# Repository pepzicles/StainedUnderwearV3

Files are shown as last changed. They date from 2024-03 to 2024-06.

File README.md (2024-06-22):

# Stained Underwear
### By Julia Daser and Pepi Ng

This project is awarded Grand Prize winner in University of Virginia's Open Call 'Data is Art', and is currently exhibited in U of Virginia's campus till the Dec 2024. 

Stained Underwear GIF

-------

### About the project

[Watch the video](https://www.youtube.com/watch?v=LS9jGnWLb5s)

This project aims to highlight the amount of time, resources and labour one spends coping with menstruation.

Our project sheds light on the often hidden and stigmatized inconveniences people face throughout their lifetime because of menstruation. We thus wish to proudly take ownership of our personal experiences with menstruation, and spark greater conversations around female reproductive health.

Pepi first collected the number of times in which they scrubbed individual underwear stained with menstrual blood over the course of 11 days. They also recorded the time in which they scrubbed their underwear each day. You can view this data in the CSV file in the "Menstrual Data" folder.

We then coded the robotic arm to scrub one of our (actual) period-stained underwear the respective number of times at the respective times of day. At the end of the 11 days, the dataset automatically starts again at Day 0. 

### Materials used

Robot Arm:
- 3 x [Servo Motors](https://www.hiwonder.com/products/ld-220mg?_pos=1&_sid=52fc990bb&_ss=r)
- 3D-printed Robot Arm base, middle and top
- M3 Screws
- [Clothes Scrubber](https://www.amazon.com/gp/product/B0CSWVYRTL/ref=ewc_pr_img_1?smid=A2RP8HJO7IWQV2&psc=1)

Sink:
- [Sink Base](https://www.amazon.com/gp/product/B0BXDFKQ64/ref=ppx_yo_dt_b_asin_title_o00_s00?ie=UTF8&psc=1)
- 3D-printed faucet and funnel
- Watertank [Food Storage](https://www.amazon.com/gp/product/B0030MY2Y0/ref=ewc_pr_img_1?smid=ATVPDKIKX0DER&th=1)
- [Waterpump](https://www.amazon.com/Gikfun-Aquarium-Cooled-Diaphragm-EK1856/dp/B0744FWNFR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)

Electronics:
- Arduino Uno
- 1000μF Capacitor
- [Precision RTC](https://www.adafruit.com/product/5188) (Clock)
- 6V 5A power supply
- Transistor 2n2222a

### Personalizing the project
Feel free to modify the project by editing the code/ 3D models/ dataset to suit your needs.

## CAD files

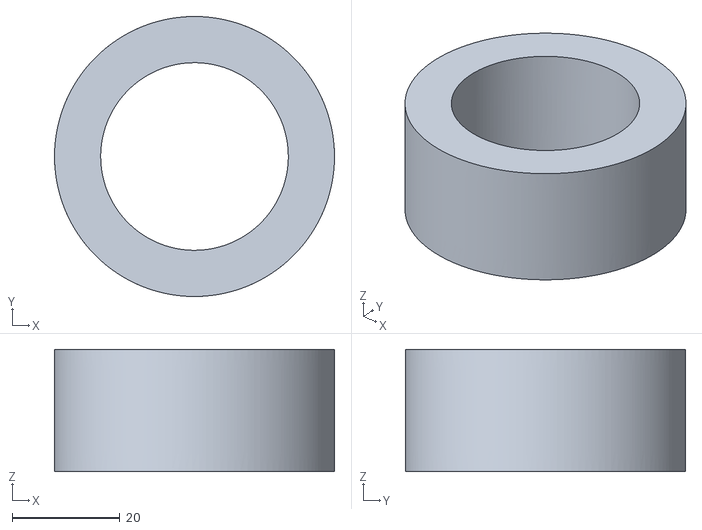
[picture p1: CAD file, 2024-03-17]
3D Models/Faucet/FaucetStopper.stl
51.9 x 51.9 x 22.6

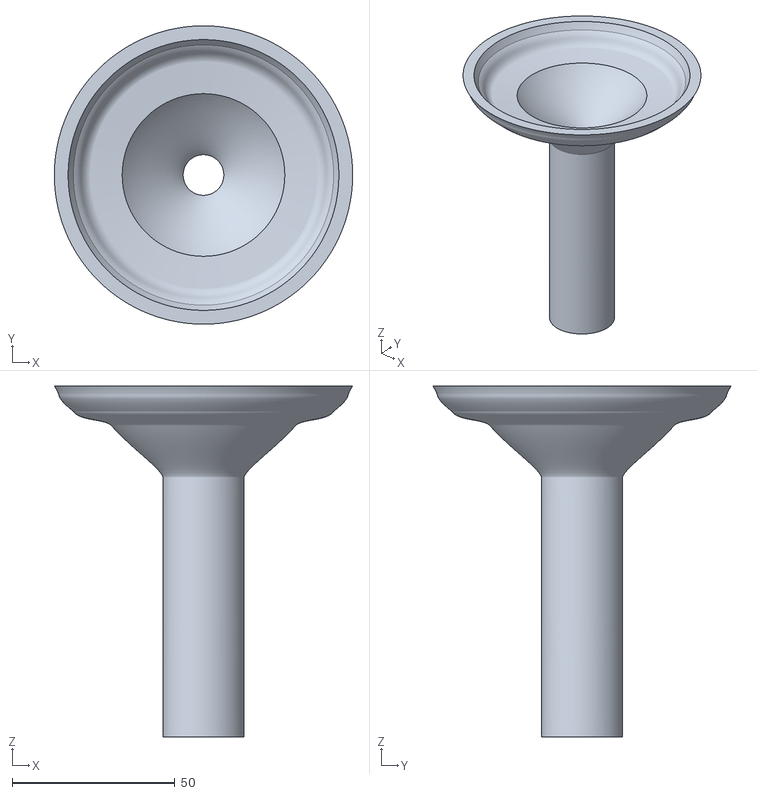
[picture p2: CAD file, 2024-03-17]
3D Models/Funnel.stl
91.7 x 91.7 x 107.9

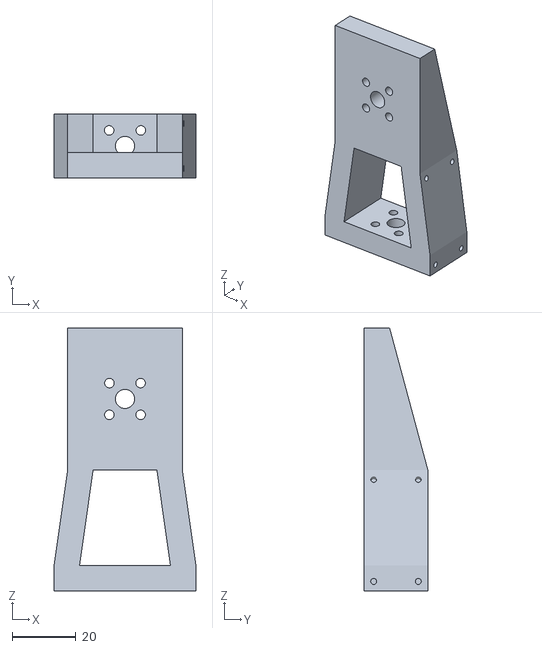
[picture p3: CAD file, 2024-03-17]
3D Models/Robot/Top.stl
44.5 x 20.0 x 82.5

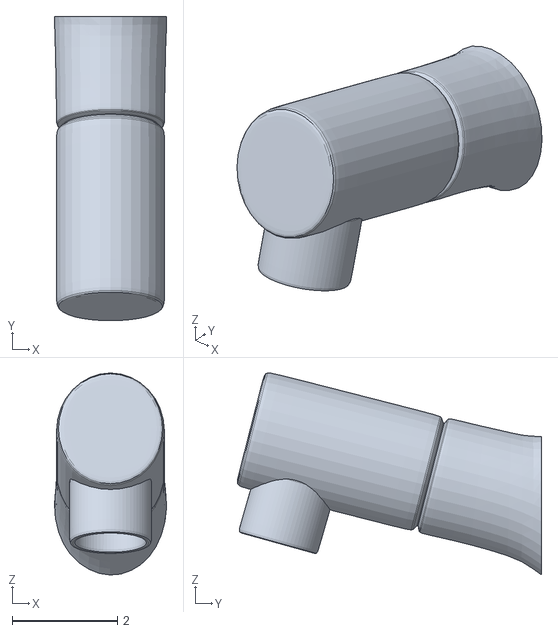
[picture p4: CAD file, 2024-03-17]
3D Models/Faucet/FaucetFront.stl
2.13 x 5.80 x 3.85

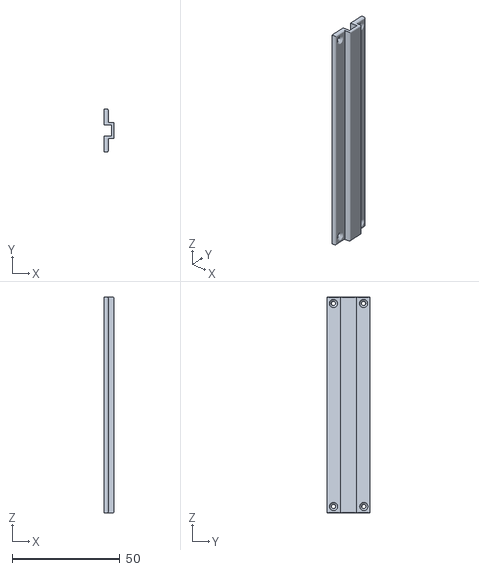
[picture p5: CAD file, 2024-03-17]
3D Models/Robot/WireHolderMiddle.stl
4.69 x 20.0 x 100.0

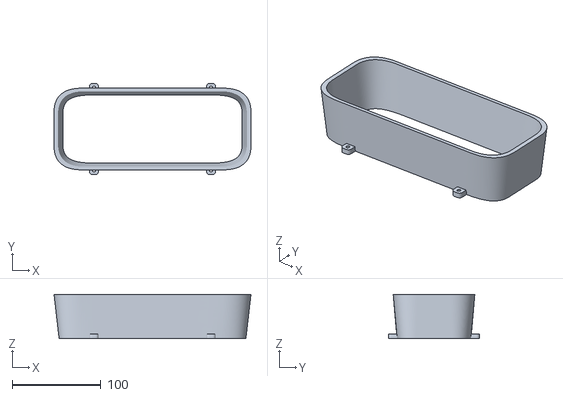
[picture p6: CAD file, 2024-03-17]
3D Models/WaterTankHolder.stl
222.3 x 102.7 x 50.0

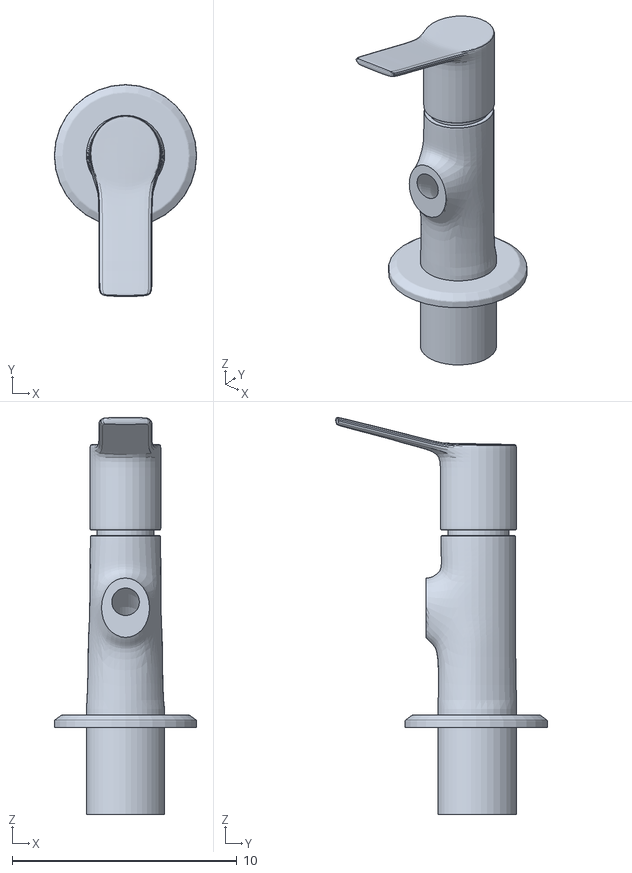
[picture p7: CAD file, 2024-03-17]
3D Models/Faucet/Faucet.stl
6.33 x 9.42 x 17.7

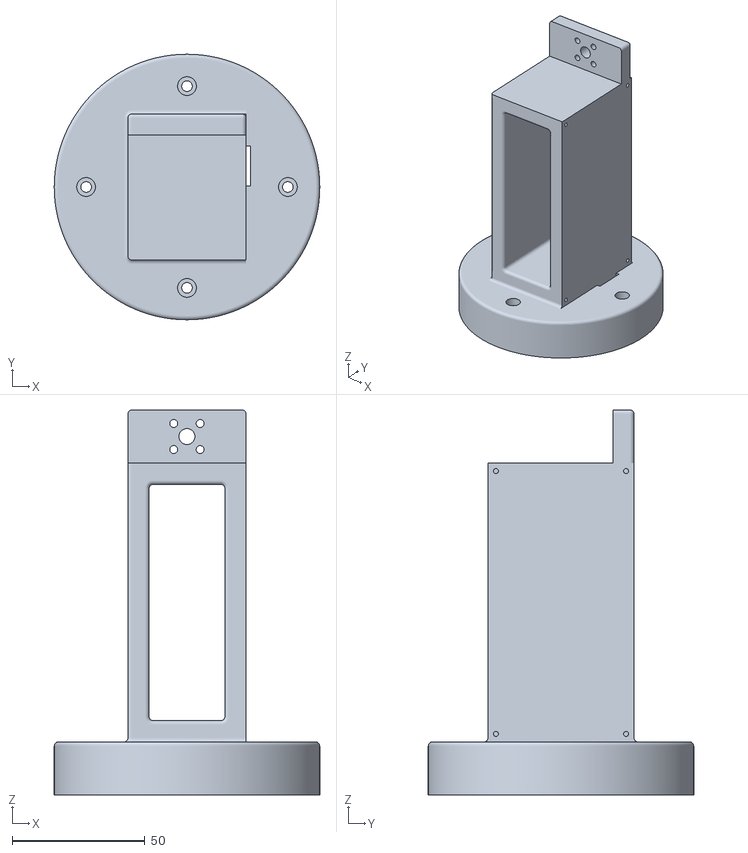
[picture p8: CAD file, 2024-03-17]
3D Models/Robot/Base.stl
100.0 x 100.0 x 145.0

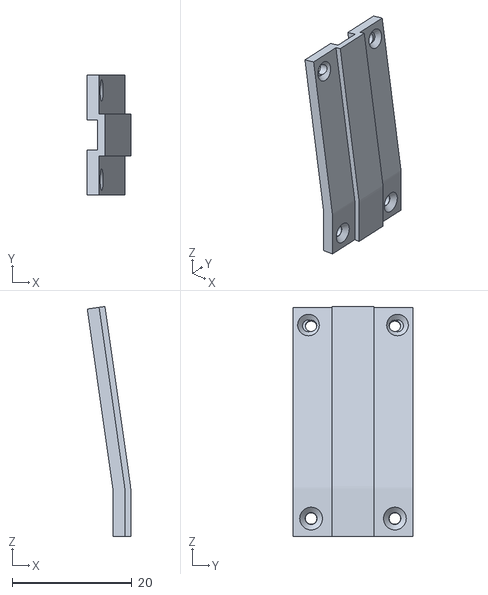
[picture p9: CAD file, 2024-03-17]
3D Models/Robot/WireHolderTop.stl
7.27 x 20.0 x 38.4

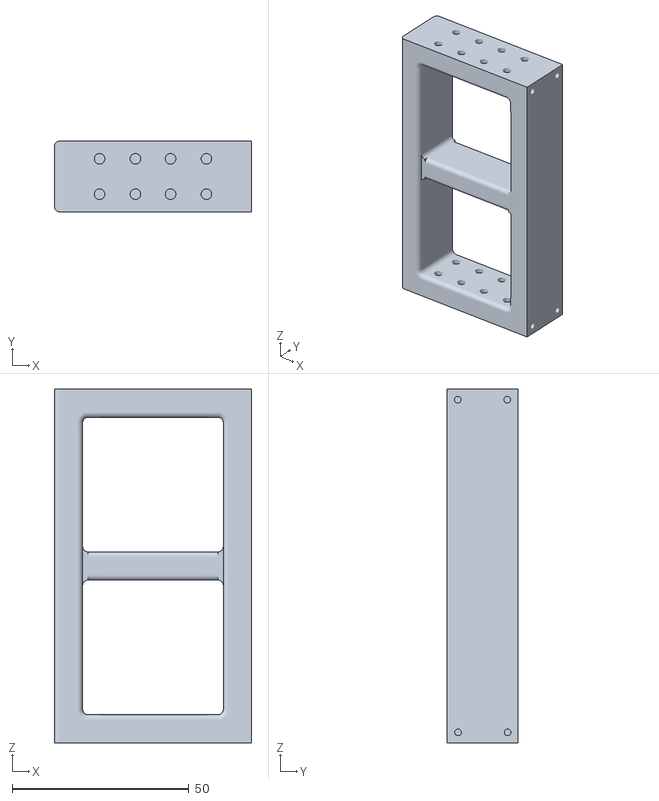
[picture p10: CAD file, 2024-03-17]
3D Models/Robot/Middle.stl
55.7 x 20.0 x 100.0

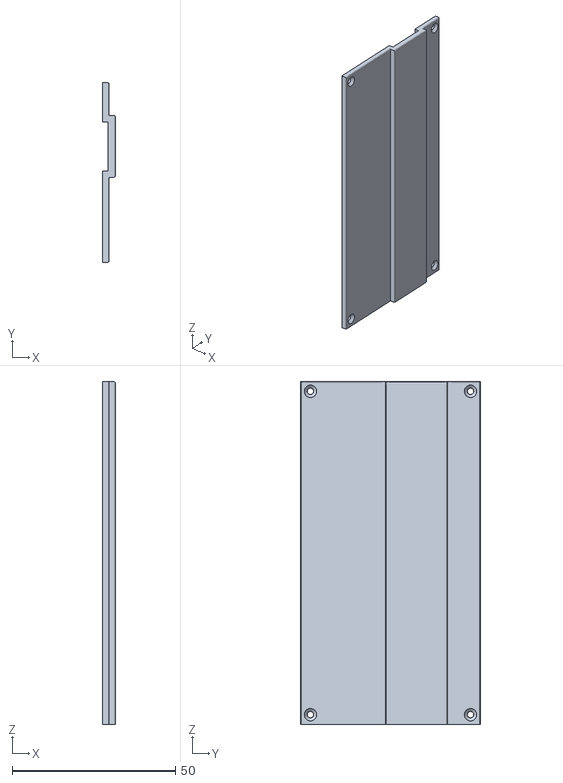
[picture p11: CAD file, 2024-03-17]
3D Models/Robot/WireHolderBase.stl
3.91 x 55.0 x 105.0

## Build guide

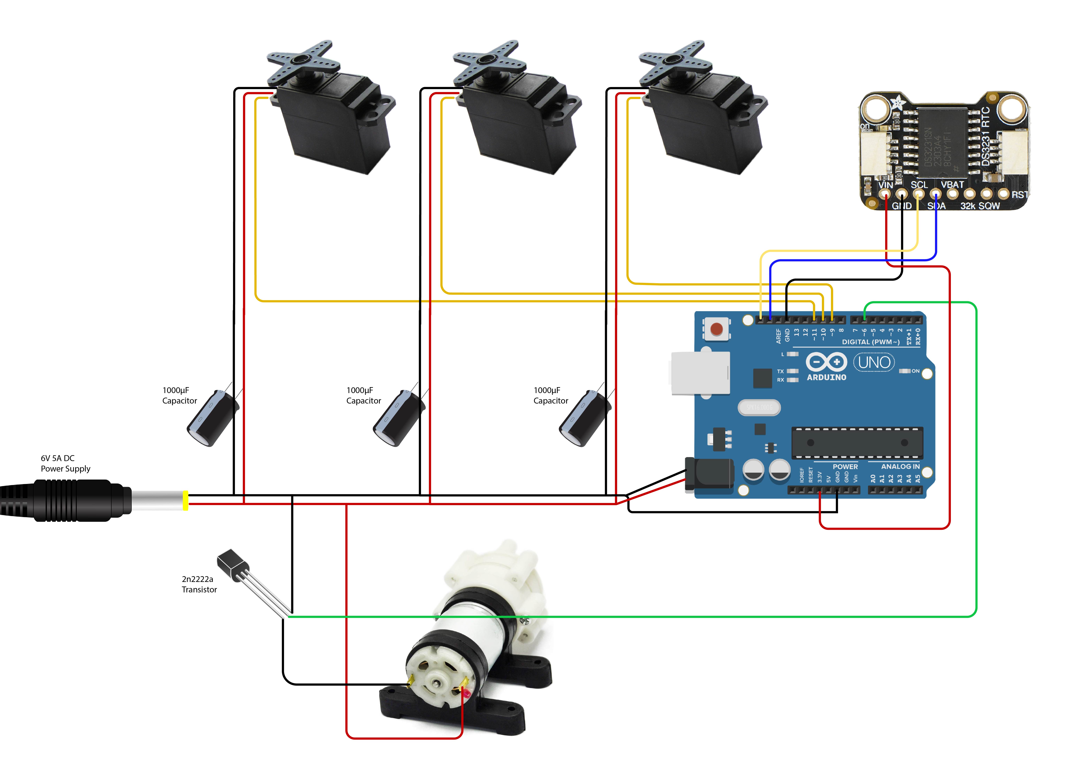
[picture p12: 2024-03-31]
Wiring Diagram.jpg

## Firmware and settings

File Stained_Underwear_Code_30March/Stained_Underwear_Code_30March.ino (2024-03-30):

#include <Servo.h>
#include <Wire.h>
#include "RTClib.h"

RTC_DS3231 rtc;

// Define servo objects
Servo servoBottom;
Servo servoMiddle;
Servo servoTop;

// Define the pins for the servos
const int relayPin = 6;
const int servoBottomPin = 9;
const int servoMiddlePin = 10;
const int servoTopPin = 11;

// Define the angles for movement
const int bottomMotorDownPosition = 48;
const int bottomMotorUpPosition = 10;

const int middleMotorDownPosition = 42;
const int middleMotorUpPosition = 20;

const int topMotorMiddlePosition = 85;
const int topMotorBackPosition = 45;
const int topMotorFrontPosition = 125;
const int topMotorNoHittingPosition = 40;
const int topMotorDefaultPosition = 60;

struct Day {
  int h;
  int m;
  int scrubs;
};

Day one;
Day two;
Day three;
Day four;
Day five;
Day six;
Day seven;
Day eight;
Day nine;
Day ten;
Day eleven;
Day twelve;
Day thirteen;
Day fourteen;
Day fifteen;

int cycle_day = 1;
int current_hour;
int current_minute;
int day_switched = false;

bool clean_now = true;

void setup() {

  one.h = 15;
  one.m = 43;
  one.scrubs = 100;

  two.h = 16;
  two.m = 12;
  two.scrubs = 98;

  three.h = 19;
  three.m = 30;
  three.scrubs = 70;

  four.h = 15;
  four.m = 01;
  four.scrubs = 75;

  five.h = 14;
  five.m = 49;
  five.scrubs = 93;

  six.h = 16;
  six.m = 28;
  six.scrubs = 82;

  seven.h = 15;
  seven.m = 16;
  seven.scrubs = 90;

  eight.h = 14;
  eight.m = 35;
  eight.scrubs = 78;

  nine.h = 13;
  nine.m = 45;
  nine.scrubs = 87;

  ten.h = 13;
  ten.m = 56;
  ten.scrubs = 80;

  eleven.h = 13;
  eleven.m = 05;
  eleven.scrubs = 110;

  twelve.h = 15;
  twelve.m = 12;
  twelve.scrubs = 120;

  thirteen.h = 14;
  thirteen.m = 45;
  thirteen.scrubs = 89;

  fourteen.h = 15;
  fourteen.m = 01;
  fourteen.scrubs = 100;

  fifteen.h = 19;
  fifteen.m = 07;
  fifteen.scrubs = 98;

  pinMode(relayPin, OUTPUT);
  digitalWrite(relayPin, LOW);

  
  servoTop.write(topMotorNoHittingPosition); //start from No Hitting for top motor
  servoTop.attach(servoTopPin);
  delay(500);

  servoBottom.write(bottomMotorUpPosition);
  servoBottom.attach(servoBottomPin);
  delay(500);

  servoMiddle.write(middleMotorUpPosition);
  servoMiddle.attach(servoMiddlePin);
  delay(500);

  delay(3000);

  //Make water in tubes go all the way to the faucet mouth
  digitalWrite(relayPin, HIGH);
  delay(10000);
  digitalWrite(relayPin, LOW);
  delay(1000);
  
  cleaning(1); // test running the water pump and the robotic arm one time

  
}

void loop() {

  if (rtc.begin()) {
    DateTime now = rtc.now();
    current_hour = now.hour();
    current_minute = now.minute();

    if (cycle_day == 1 && current_hour == one.h && current_minute == one.m) {
      cleaning(one.scrubs);
    }

    else if (cycle_day == 2 && current_hour == two.h && current_minute == two.m) {
      cleaning(two.scrubs);
    }

    else if (cycle_day == 3 && current_hour == three.h && current_minute == three.m) {
      cleaning(three.scrubs);
    }

    else if (cycle_day == 4 && current_hour == four.h && current_minute == four.m) {
      cleaning(four.scrubs);
    }

    else if (cycle_day == 5 && current_hour == five.h && current_minute == five.m) {
      cleaning(five.scrubs);
    }

    else if (cycle_day == 6 && current_hour == six.h && current_minute == six.m) {
      cleaning(six.scrubs);
    }

    else if (cycle_day == 7 && current_hour == seven.h && current_minute == seven.m) {
      cleaning(seven.scrubs);
    }

    else if (cycle_day == 8 && current_hour == eight.h && current_minute == eight.m) {
      cleaning(eight.scrubs);
    }

    else if (cycle_day == 9 && current_hour == nine.h && current_minute == nine.m) {
      cleaning(nine.scrubs);
    }

    else if (cycle_day == 10 && current_hour == ten.h && current_minute == ten.m) {
      cleaning(ten.scrubs);
    }

    else if (cycle_day == 11 && current_hour == eleven.h && current_minute == eleven.m) {
      cleaning(eleven.scrubs);
    }

    else if (cycle_day == 12 && current_hour == twelve.h && current_minute == twelve.m) {
      cleaning(twelve.scrubs);
    }

    else if (cycle_day == 13 && current_hour == thirteen.h && current_minute == thirteen.m) {
      cleaning(thirteen.scrubs);
    }

    else if (cycle_day == 14 && current_hour == fourteen.h && current_minute == fourteen.m) {
      cleaning(fourteen.scrubs);
    }

    else if (cycle_day == 15 && current_hour == fifteen.h && current_minute == fifteen.m) {
      cleaning(fifteen.scrubs);
    }

    // organizing how we count:
    if (day_switched == false && current_hour == 23 && current_minute == 59) {
      cycle_day += 1;
      day_switched = true;
    }

    if (current_hour == 0 && current_minute == 0) {
      day_switched = false; // resetting value for the day
      clean_now = true;
    }

    if (cycle_day == 16) {
      cycle_day = 1;
    }
  }

  delay(1000);
}

void cleaning(int swipeNum) {
  if (clean_now == true) {
    //Turn on and off water pump
    waterPump();
    clean_now = false;

    //Move robot arm Down
    downMovement();

    //Start Scrubbing
    for (int i = 0; i < (swipeNum - 2) ; i++) {
      backAndForth();
    }

    //Move robot arm Up
    upMovement();
  }
}

void backAndForth() {
  //TOP MOTOR: Middle to Front
  for (int i = topMotorMiddlePosition; i <= topMotorFrontPosition; i++) {
    servoTop.write(i); // Move servo to the current angle
    delay(map(i, topMotorMiddlePosition, topMotorFrontPosition, 3, 20)); // Delay with decreasing interval for acceleration
  }

  // TOP MOTOR: Back to Middle
  for (int i = topMotorFrontPosition; i >= topMotorMiddlePosition; i--) {
    servoTop.write(i); // Move servo to the current angle
    delay(map(i, topMotorFrontPosition, topMotorMiddlePosition, 20, 3)); // Delay with decreasing interval for acceleration
  }

  // TOP MOTOR: Middle to Front
  for (int i = topMotorMiddlePosition; i >= topMotorBackPosition; i--) {
    servoTop.write(i); // Move servo to the current angle
    delay(map(i, topMotorMiddlePosition, topMotorBackPosition, 3, 20)); // Delay with decreasing interval for acceleration
  }

  // TOP MOTOR: Front to Center
  for (int i = topMotorBackPosition; i <= topMotorMiddlePosition; i++) {
    servoTop.write(i); // Move servo to the current angle
    delay(map(i, topMotorBackPosition, topMotorMiddlePosition, 20, 3)); // Delay with decreasing interval for acceleration
  }
}


void waterPump() {
  delay(1000);
  digitalWrite(relayPin, HIGH);
  delay(5000);
  digitalWrite(relayPin, LOW);
  delay(1000);
}

void downMovement() {

  // TOP MOTOR: Default to NoHittingPosition
  for (int i = topMotorDefaultPosition; i >= topMotorNoHittingPosition; i--) {
    servoTop.write(i); // Move servo to the current angle
    delay(map(i, topMotorDefaultPosition, topMotorNoHittingPosition, 3, 20)); // Delay with decreasing interval for acceleration
  }

  //BOTTOM MOTOR: Down Movement
  for (int i = bottomMotorUpPosition; i <= bottomMotorDownPosition; i ++) {
    servoBottom.write(i);
    delay(50);
  }

  // MIDDLE MOTOR: Down Movement
  for (int i = middleMotorUpPosition; i <= middleMotorDownPosition; i ++) {
    servoMiddle.write(i);
    delay(50);
  }

  // TOP MOTOR: NoHittingPosition to Middle
  for (int i = topMotorNoHittingPosition; i <= topMotorMiddlePosition; i++) {
    servoTop.write(i); // Move servo to the current angle
    delay(map(i, topMotorNoHittingPosition, topMotorMiddlePosition, 20, 3)); // Delay with decreasing interval for acceleration
  }
}

void upMovement() {

  //TOP MOTOR: Middle to Back
  for (int i = topMotorMiddlePosition; i <= topMotorFrontPosition; i++) {
    servoTop.write(i); // Move servo to the current angle
    delay(map(i, topMotorMiddlePosition, topMotorFrontPosition, 3, 20)); // Delay with decreasing interval for acceleration
  }

  // TOP MOTOR: Back to Middle
  for (int i = topMotorFrontPosition; i >= topMotorMiddlePosition; i--) {
    servoTop.write(i); // Move servo to the current angle
    delay(map(i, topMotorFrontPosition, topMotorMiddlePosition, 20, 3)); // Delay with decreasing interval for acceleration
  }

  // TOP MOTOR: Middle to NoHittingPosition
  for (int i = topMotorMiddlePosition; i >= topMotorNoHittingPosition; i--) {
    servoTop.write(i); // Move servo to the current angle
    delay(map(i, topMotorMiddlePosition, topMotorNoHittingPosition, 3, 20)); // Delay with decreasing interval for acceleration
  }

  // MIDDLE MOTOR: Up Movement
  for (int i = middleMotorDownPosition; i >= middleMotorUpPosition; i --) {
    servoMiddle.write(i);
    delay(100);
  }

  //BOTTOM MOTOR: Up Movement
  for (int i = bottomMotorDownPosition; i >= bottomMotorUpPosition; i --) {
    servoBottom.write(i);
    delay(100);
  }

  // TOP MOTOR: NoHittingPosition to Default
  for (int i = topMotorNoHittingPosition; i <= topMotorDefaultPosition; i++) {
    servoTop.write(i); // Move servo to the current angle
    delay(map(i, topMotorNoHittingPosition, topMotorDefaultPosition, 20, 3)); // Delay with decreasing interval for acceleration
  }
}
